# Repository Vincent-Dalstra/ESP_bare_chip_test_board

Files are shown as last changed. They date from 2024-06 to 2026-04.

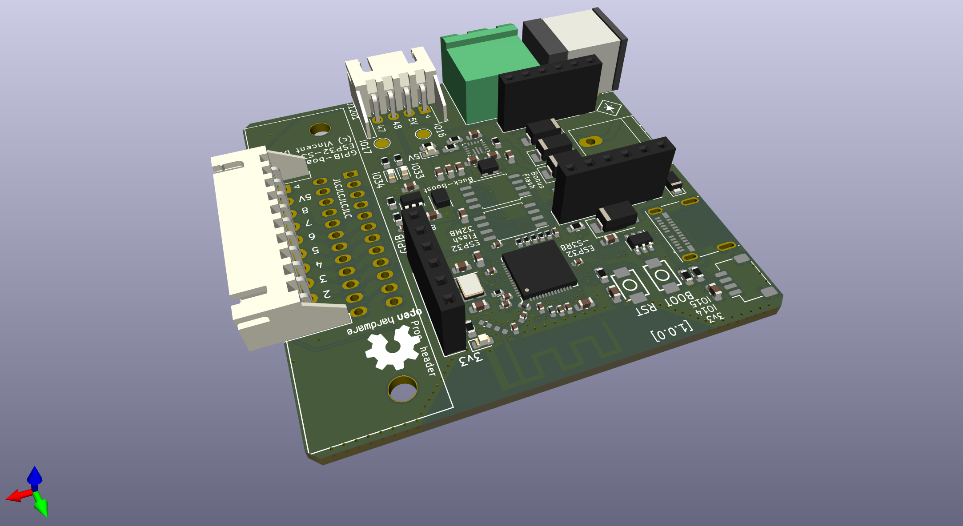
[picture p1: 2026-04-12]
Releases/v1.0.0/ESP_bare_chip_test_board_v1.1.0_corner_view.png

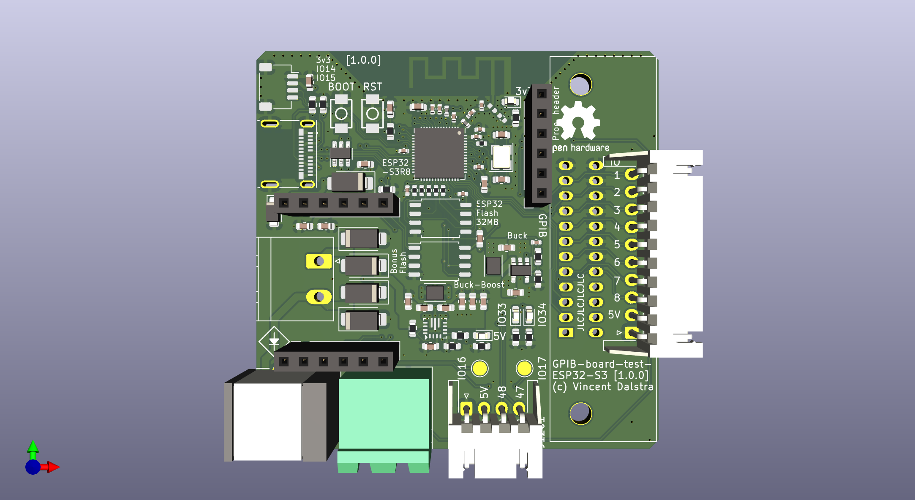
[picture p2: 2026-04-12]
Releases/v1.0.0/ESP_bare_chip_test_board_v1.1.0_top_view.png

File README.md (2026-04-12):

# ESP32 bare-chip test board / GPIB interface  #

This board primarily served as a practice design, to see if I could make a functioning esp32-s3 chip based circuit (not module!).
However, I prefer my boards to have a useful purpose rather than just being a paperweight, so decided to combine it with something else I was working on, which was to make an integrated verison of the boards in
https://github.com/Vincent-Dalstra/ESP32-GPIB-pcb, which saves having to use dev boards for this.

The code that it's expected to run can be found at https://github.com/douardda/AR488-ESP32
It is a very useful project, which allows an ESP32 to control various old (and new!) test-equipment.

## Features ##

* Versatile power-input options
  * USB-C port
  * Choice of barrel-jack or 5.08mm screw terminals
    * Works with either polarity - bridge rectifier
    * 3-17V input range
  * If both USB-C and another source are provided, the higher-voltage will be used.
* Wired or Wireless network connectivity
  * Slot for SPI Ethernet adapter (USR-ES1, based on W5500 chip)
  * WiFi/Bluetooth Antenna
* Non-volatile storage
  * 16MB flash via high-speed QIO connection
    * Used to store program code
    * Excess can be used for other purposes
  * 16MB flash via SPI bus
    * Shares the bus with Ethernet adapter
* Programmeable via USB-C port or (optional) 6pin UART header
* Connectors:
  * 24pin connector for GPIB, with 16 IO pins OR
    * alternatively a 10pin 2.50mm JST connector (8x IO, 5V, Gnd)
  * 4pin 1.00mm Piicodev-compatible connector
  * 4pin 2.50mm JST (2x IO, 5V, Gnd)
* Misc.
  * 2x Yellow Indicator LED's
  * 2x Test points that can be soldered to.

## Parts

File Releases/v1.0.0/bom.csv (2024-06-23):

Comment | Designator | Footprint | LCSC
10kΩ | R101,R102,R201,R202 | Resistor_SMD:R_0603_1608Metric | C25804
YELLOW | D101,D102 | LED_SMD:LED_0603_1608Metric | C72038
22uF/6.3V | C203,C1003,C1301,C1302,C1402 | Capacitor_SMD:C_0603_1608Metric | C59461
Conn_01x04 | J1501 | Connector_JST:JST_SH_SM04B-SRSS-TB_1x04-1MP_P1.00mm_Horizontal | C145956
100nF/50V | C201,C1401 | Capacitor_SMD:C_0603_1608Metric | C14663
GREEN | D201,D507 | LED_SMD:LED_0603_1608Metric | C779453
SW_Push | SW201,SW202 | Button_Switch_SMD_custom:SW_PUSHBUTTON_2PIN_SMD_3×4×2.0 | C720477
1uF | C304,C305,C307 | Capacitor_SMD:C_0402_1005Metric | C52923
40MHz | Q301 | Crystal:Crystal_SMD_3225-4Pin_3.2x2.5mm | C379787
10pF | C301,C302 | Capacitor_SMD:C_0603_1608Metric | C1634
0 | R302,R303,R304,R305,R306 | Resistor_SMD:R_0402_1005Metric | C203078
10nF | C308 | Capacitor_SMD:C_0402_1005Metric | C15195
W25Q128JVS | U301,U1401 | Package_SO:SOIC-8_5.23x5.23mm_P1.27mm | C97521
2.0nH(0.1nH) | L301 | Inductor_SMD:L_0402_1005Metric | C43365
0.1uF | C306,C309,C310,C311,C312 | Capacitor_SMD:C_0402_1005Metric | C307331
10uF/10V | C303,C1001,C1004,C1005,C1006,C1007 | Capacitor_SMD:C_0603_1608Metric | C19702
24nH | R301 | Resistor_SMD:R_0402_1005Metric | C330863
ESP32-S3R8 | U302 | Package_DFN_QFN:QFN-56-1EP_7x7mm_P0.4mm_EP5.6x5.6mm | C2913194
1.6nH | L401 | Inductor_SMD:L_0402_1005Metric | C162539
4.7pF | C401 | Capacitor_SMD:C_0402_1005Metric | C1569
2.7pF | C402 | Capacitor_SMD:C_0402_1005Metric | C1561
SS210 | D502,D503,D504,D505,D509 | Diode_SMD:D_SMA | C14996
SMF5V0A | D501 | Diode_SMD:D_SMF | C2905637
10uF/25v | C501,C1010,C1011 | Capacitor_SMD:C_0603_1608Metric | C96446
33kΩ | R506,R1002 | Resistor_SMD:R_0603_1608Metric | C4216
680kΩ | R1004 | Resistor_SMD:R_0603_1608Metric | C25822
130kΩ | R1005 | Resistor_SMD:R_0603_1608Metric | C22795
100nF | C1012 | Capacitor_SMD:C_0603_1608Metric | C14663
TPS63070 | U1002 | Package_DFN_QFN_custom:VQFN-15-HR_2.5x3mm_P0.5mm | C109322
100kΩ | R1003 | Resistor_SMD:R_0603_1608Metric | C25803
1.5uH | L1003 | Inductor_SMD:L_Changjiang_FNR252012S | C5832371
2.2uH | L1001 | Inductor_SMD:L_Changjiang_FNR252012S | C5832372
22pF | C1002 | Capacitor_SMD:C_0402_1005Metric | C1555
150kΩ | R1001 | Resistor_SMD:R_0603_1608Metric | C22807
TLV62569DBV | U1001 | Package_TO_SOT_SMD:SOT-23-5 | C141836
1.5kΩ | R1301 | Resistor_SMD:R_0603_1608Metric | C22843
D1213A-04TS-7 | U801 | Package_TO_SOT_SMD:TSOT-23-6 | C460588
5.1kΩ | R601,R602 | Resistor_SMD:R_0603_1608Metric | C23186
USB_C_Receptacle | J801 | Connector_USB:USB_C_Receptacle_Molex_105450-0101 | C134092

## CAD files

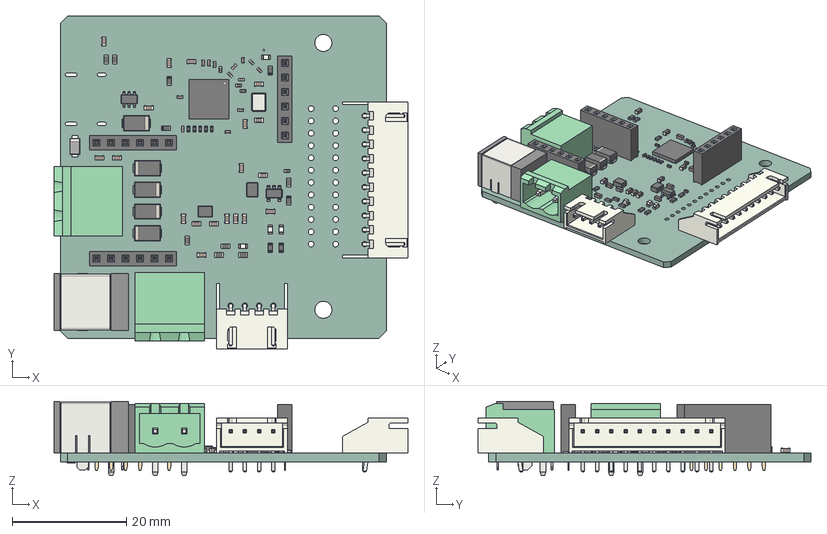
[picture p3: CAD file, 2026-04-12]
Releases/v1.0.0/ESP_bare_chip_test_board.step
62.0 x 58.4 x 13.0 mm
BarrelJack_CUI_PJ-063AH_Horizontal
C_0402_1005Metric x 13
R_0603_1608Metric x 13
C_0603_1608Metric x 19
L_Changjiang_FNR252012S x 2
JST_XH_S10B-XH-A-1_1x10_P2.50mm_Horizontal
L_0402_1005Metric x 3
PinSocket_1x06_P2.54mm_Vertical x 3
TSOT-23-6
R_0402_1005Metric x 6
D_SMA x 5
SOT-23-5
QFN-56-1EP_7x7mm_P0.4mm_EP5.6x5.6mm
D_SMF
Crystal_SMD_3225-4Pin_3.2x2.5mm
JST_XH_S4B-XH-A-1_1x04_P2.50mm_Horizontal
LED_0603_1608Metric x 4
PhoenixContact_MSTBA_2,5_2-G-5,08_1x02_P5.08mm_Horizontal x 2
ESP_bare_chip_test_board_PCB

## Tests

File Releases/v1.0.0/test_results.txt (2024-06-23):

So far, only simple intial testing has been done to verify that the board
'works', withot trying every feature in detail.

# Initial testing #

Boards arrived. Unpacked, look good.

## Power-up test ##

Plugged into USB power outlet w/ current meter
- 5V and 3v3 LED's light up ok
- Current draw reads 0.0A (<100mA)

All working as expected.

Also, touched both regulator circuits with fingers, thoroughly - no issues
- Some buck-regulators I've used would be be killed by this!

## Test code ##

Plugged into computer - shows up as /dev/ttyACM0

Used idf.py to compile and flash 'blink' sketch, after setting the blink
pin to IO33 (yellow LED), and setting it to not be an addressable LED!
- LED blinking ok
- Serial output ok

## Wifi test code ##

Compile and flashed the examples/wifi/scan to the board
- Found the local wireless network, from both AP's!
- Nearest one = single-brick wall + 8 metres

## See details about flash chip ##

Ran esptool.py flash_id

Output:

esptool.py v4.7.0
Serial port /dev/ttyACM0
Connecting....
Detecting chip type... ESP32-S3
Chip is ESP32-S3 (QFN56) (revision v0.2)
Features: WiFi, BLE, Embedded PSRAM 8MB (AP_3v3)
Crystal is 40MHz
MAC: f0:f5:bd:4a:2d:04
Uploading stub...
Running stub...
Stub running...
Manufacturer: ef
Device: 4018
Detected flash size: 16MB
Flash type set in eFuse: quad (4 data lines)
Hard resetting via RTS pin...

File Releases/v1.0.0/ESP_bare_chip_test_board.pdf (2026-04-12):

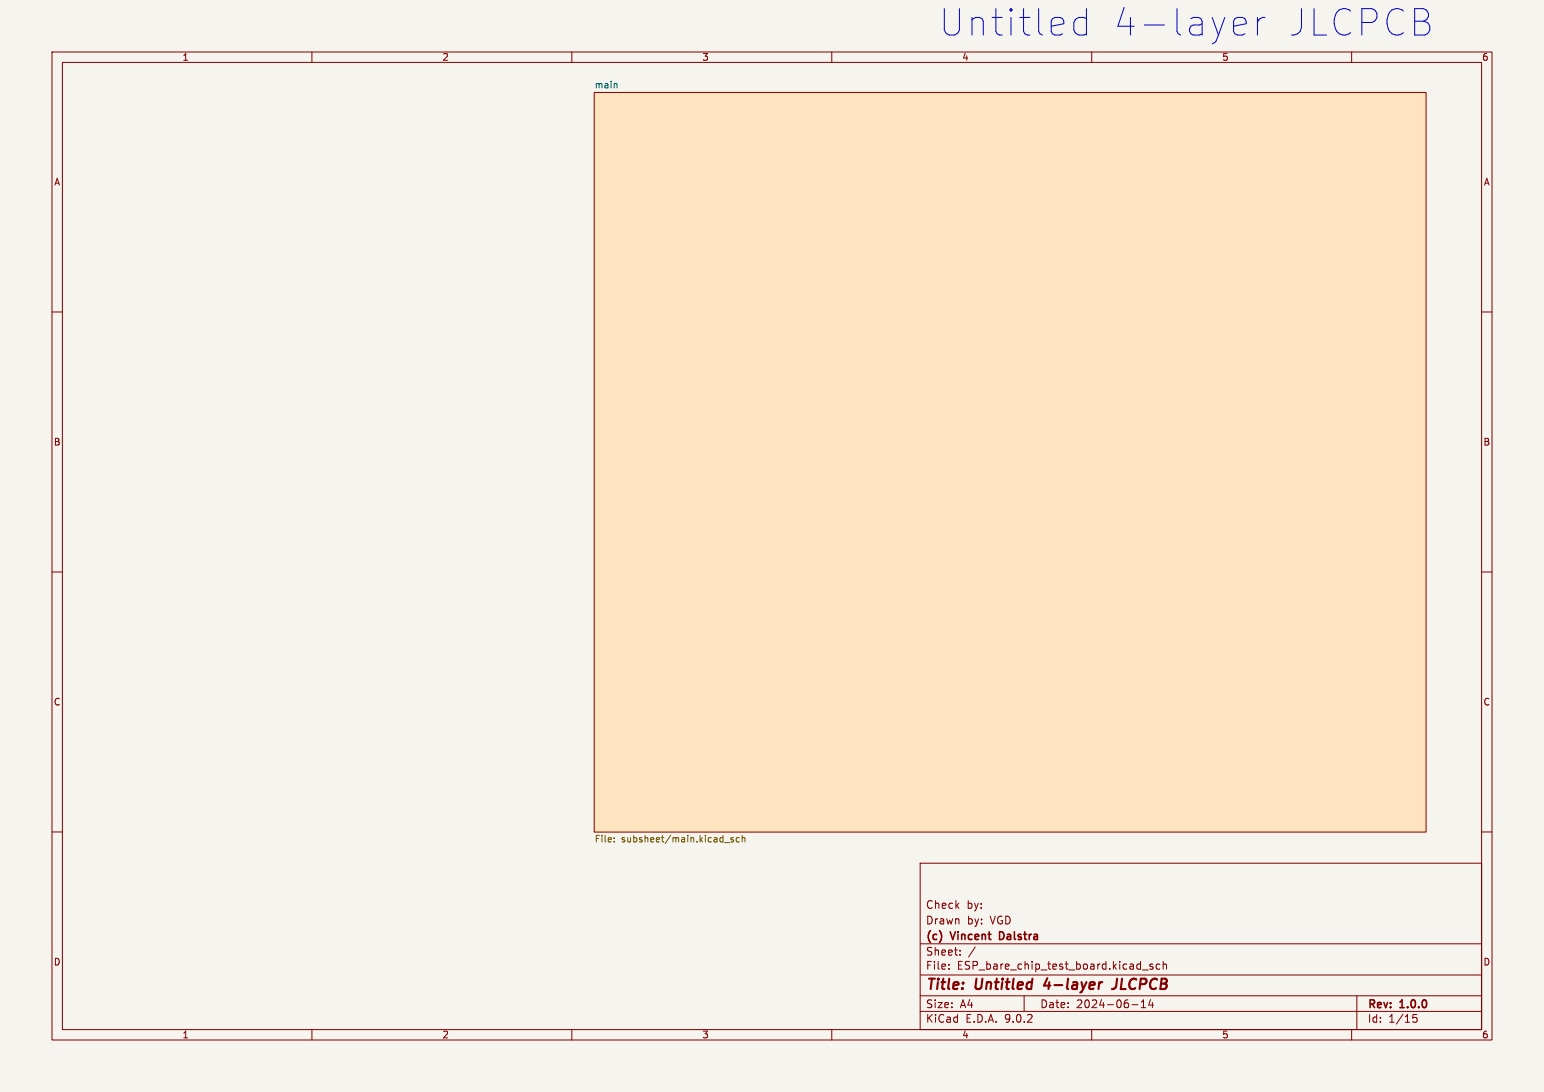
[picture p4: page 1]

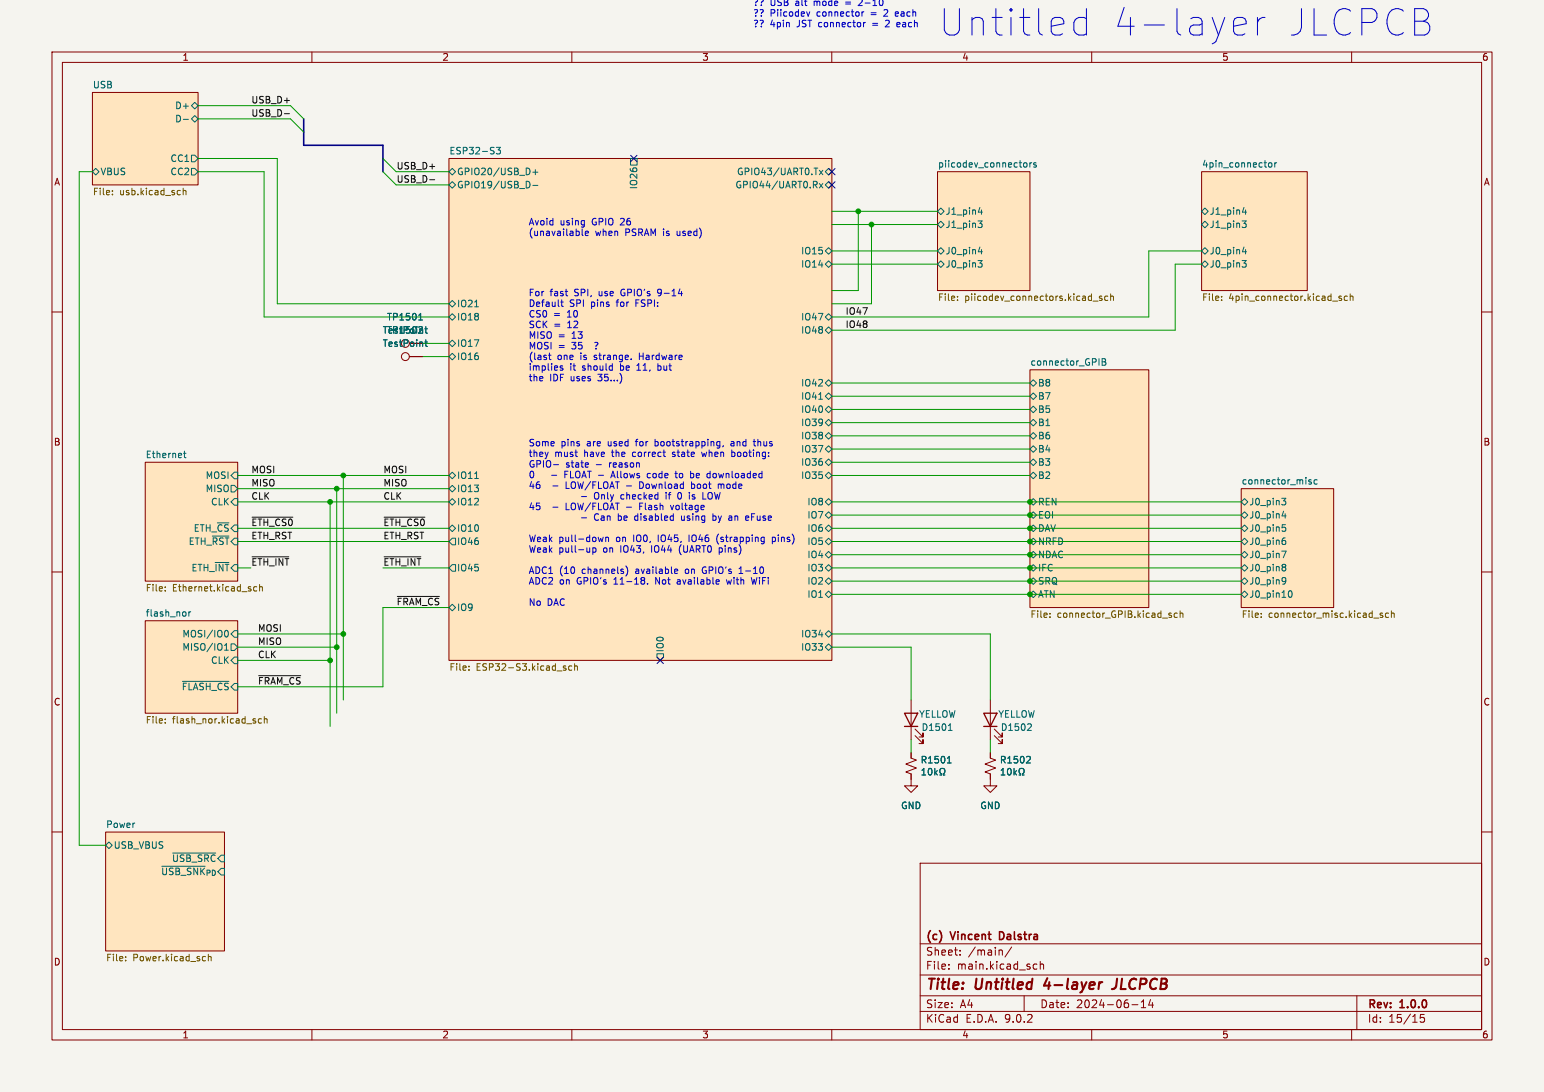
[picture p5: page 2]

(last one is strange. Hardware
the IDF uses 35...)

~{USB_SNK}_{PD} Power File: Power.kicad_sch CLK

they must have the correct state when booting: GPIO- state - reason

- Only checked if 0 is LOW

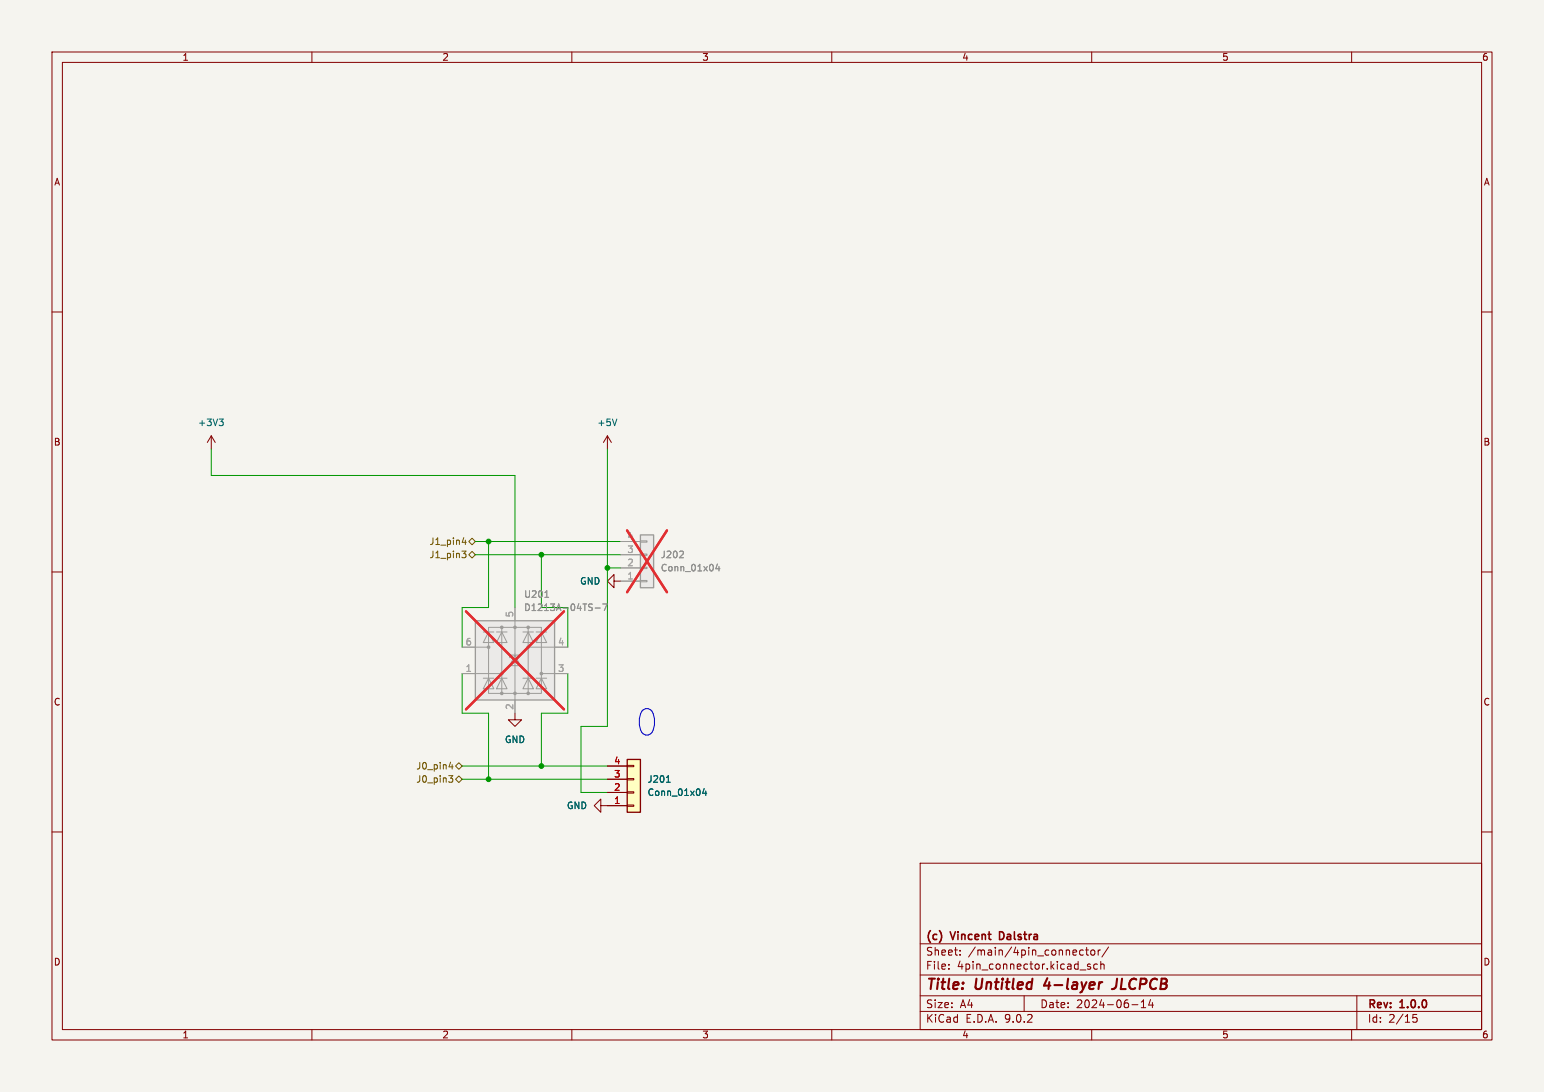
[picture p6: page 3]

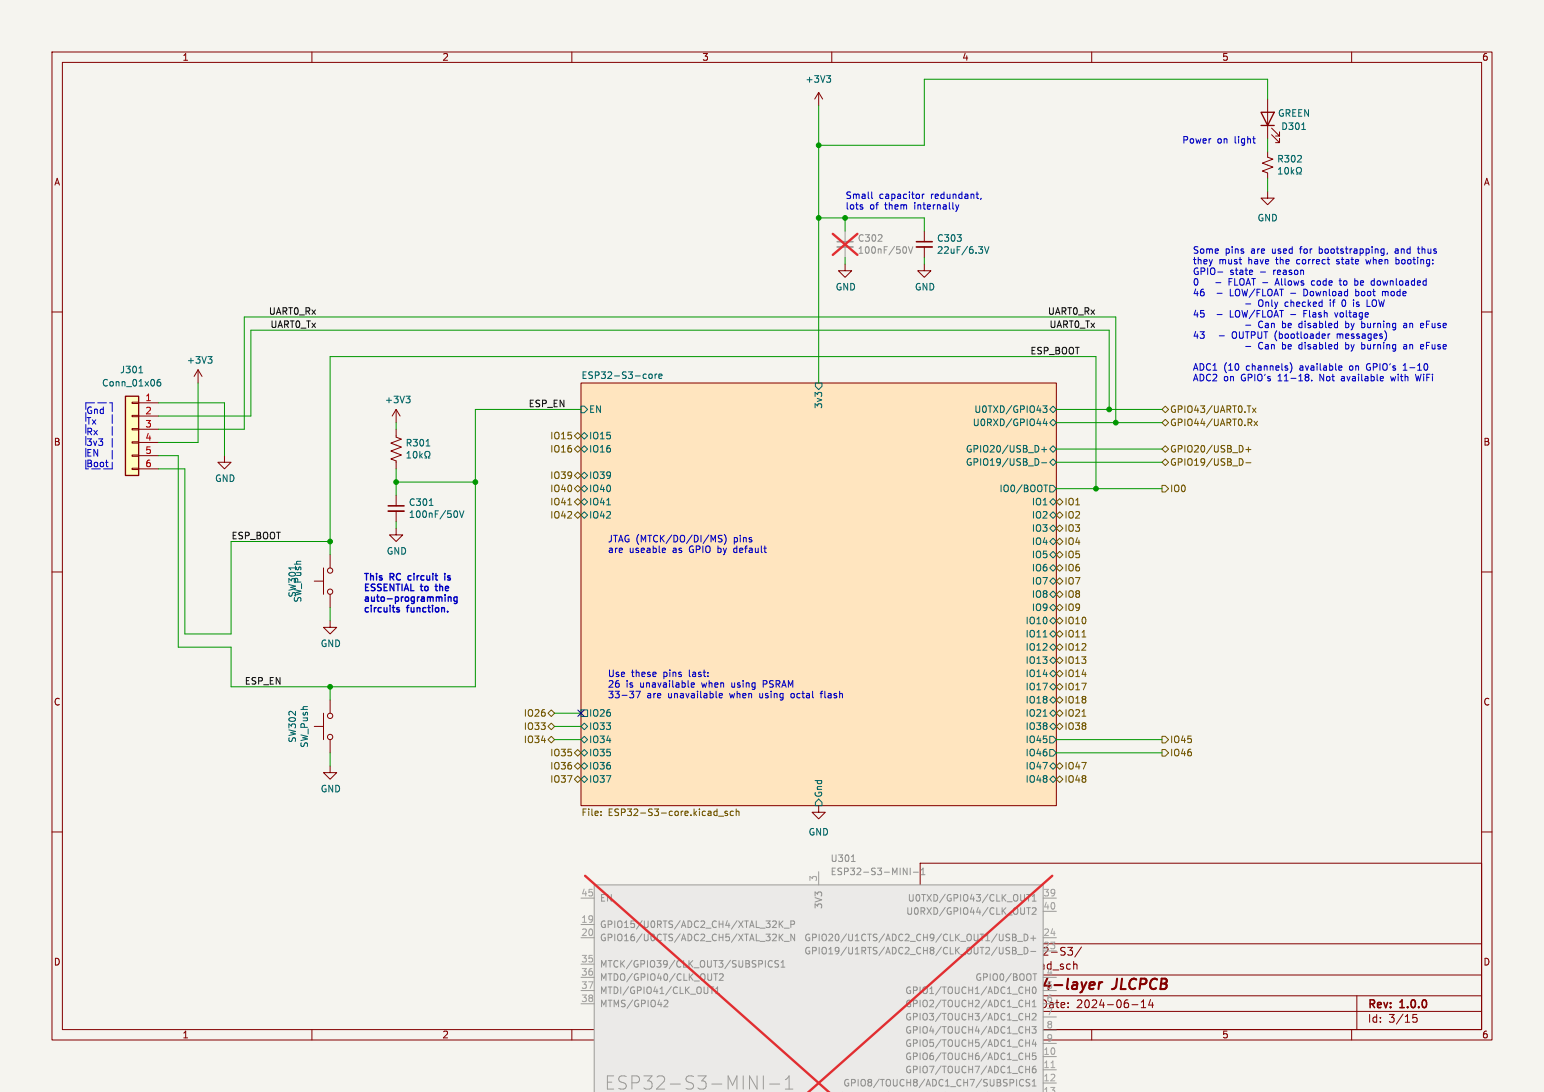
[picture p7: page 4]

they must have the correct state when booting: GPIO- state - reason

- Only checked if 0 is LOW

1 U0TXD/GPIO43/CLK_OUT1 39 U0RXD/GPIO44/CLK_OUT2 40 GPIO20/U1CTS/ADC2_CH9/CLK_OUT1/USB_D+ 24 GPIO19/U1RTS/ADC2_CH8/CLK_OUT2/USB_D- 23 GPIO0/BOOT 4 GPIO1/TOUCH1/ADC1_CH0 5 GPIO2/TOUCH2/ADC1_CH1 6 GPIO3/TOUCH3/ADC1_CH2 7 GPIO4/TOUCH4/ADC1_CH3 8 GPIO5/TOUCH5/ADC1_CH4 9 GPIO6/TOUCH6/ADC1_CH5 10 GPIO7/TOUCH7/ADC1_CH6 11 GPIO8/TOUCH8/ADC1_CH7/SUBSPICS1 12 GPIO9/TOUCH9/ADC1_CH8/FSPIHD/SUBSPIHD 13 GPIO10/TOUCH10/ADC1_CH9/FSPICS0/FSPIIO4/SUBSPICS0 14 GPIO11/TOUCH11/ADC2_CH0/FSPID/FSPIIO5/SUBSPID 15 GPIO12/TOUCH12/ADC2_CH1/FSPICLK/FSPIIO6/SUBSPICLK 16 GPIO13/TOUCH13/ADC2_CH2/FSPIQ/FSPIIO7/SUBSPIQ 17 GPIO14/TOUCH14/ADC2_CH3/FSPIWP/FSPIDQS/SUBSPIWP 18 GPIO17/U1TXD/ADC2_CH6 21 GPIO18/U1RXD/ADC2_CH7/CLK_OUT3 22 GPIO21 25 GPIO38/FSPIWP/SUBSPIWP 34 GPIO45 41 GPIO46 44 GPIO47/SPICLK_P/SUBSPICLK_P_DIFF 27 GPIO48/SPICLK_N/SUBSPICLK_N_DIFF 30 U301 ESP32-S3-MINI-1

File: ESP32-S3.kicad_sch Sheet: /main/ESP32-S3/ (c) Vincent by: VGD Dalstra Drawn

E.D.A. 9.0.2 Size: A4 | Rev: 1.0.0 | D Date: 2024-06-14 KiCad

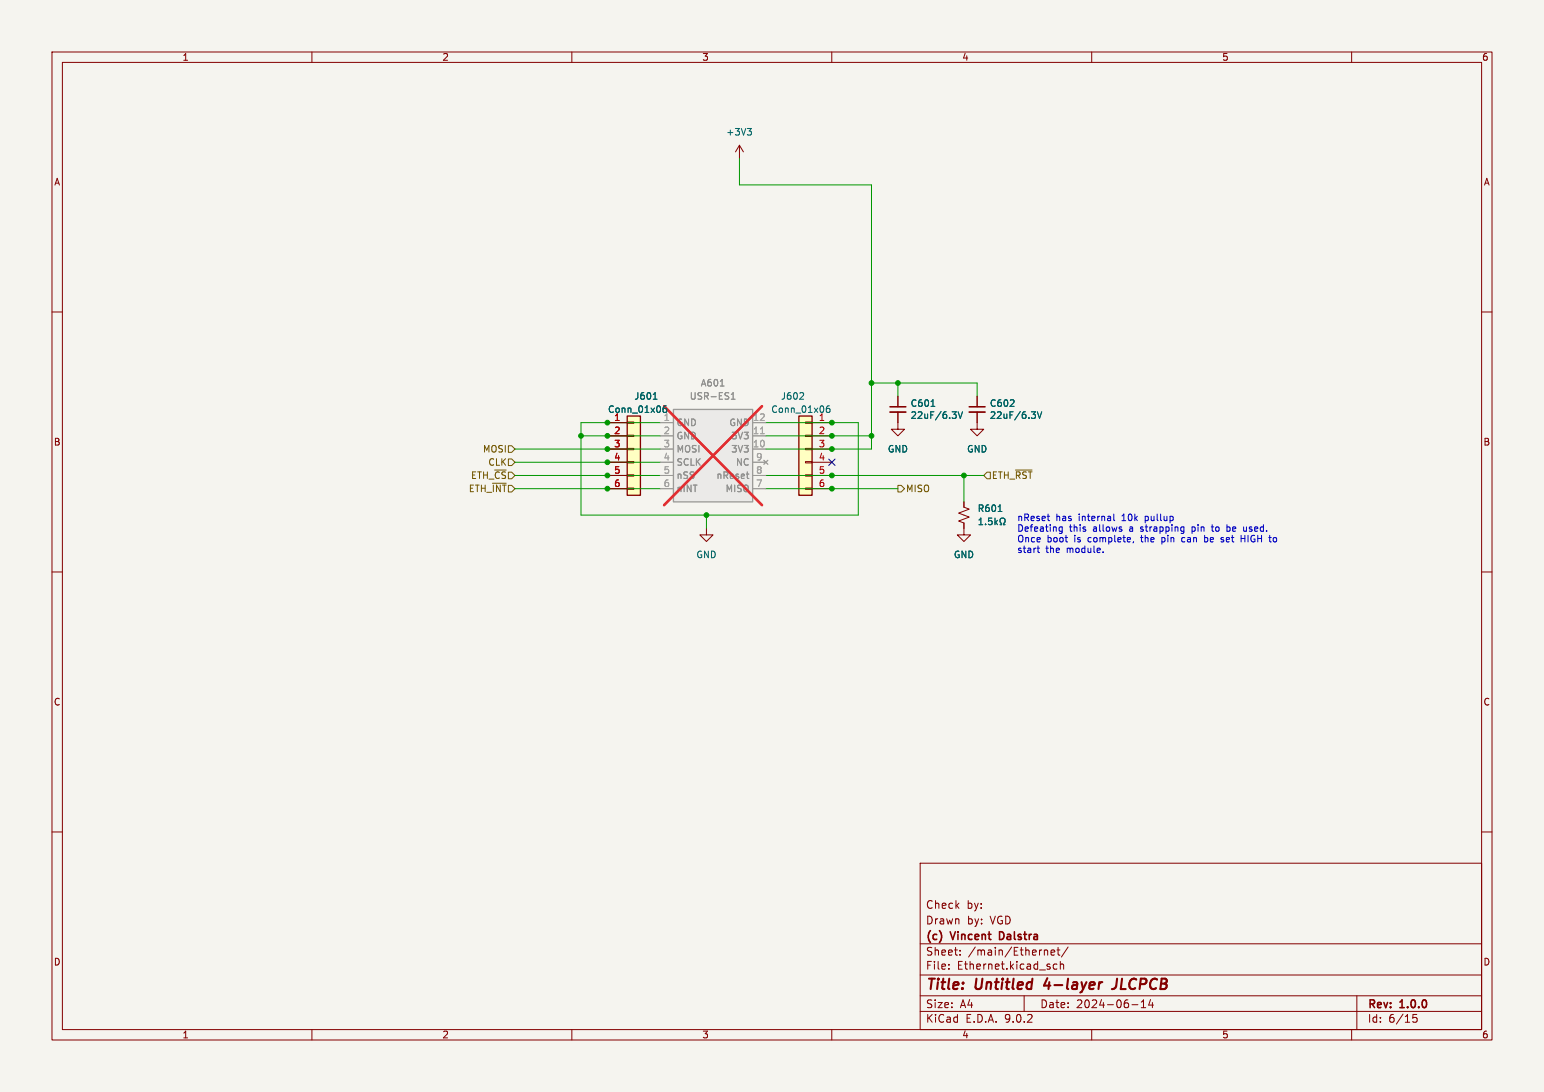
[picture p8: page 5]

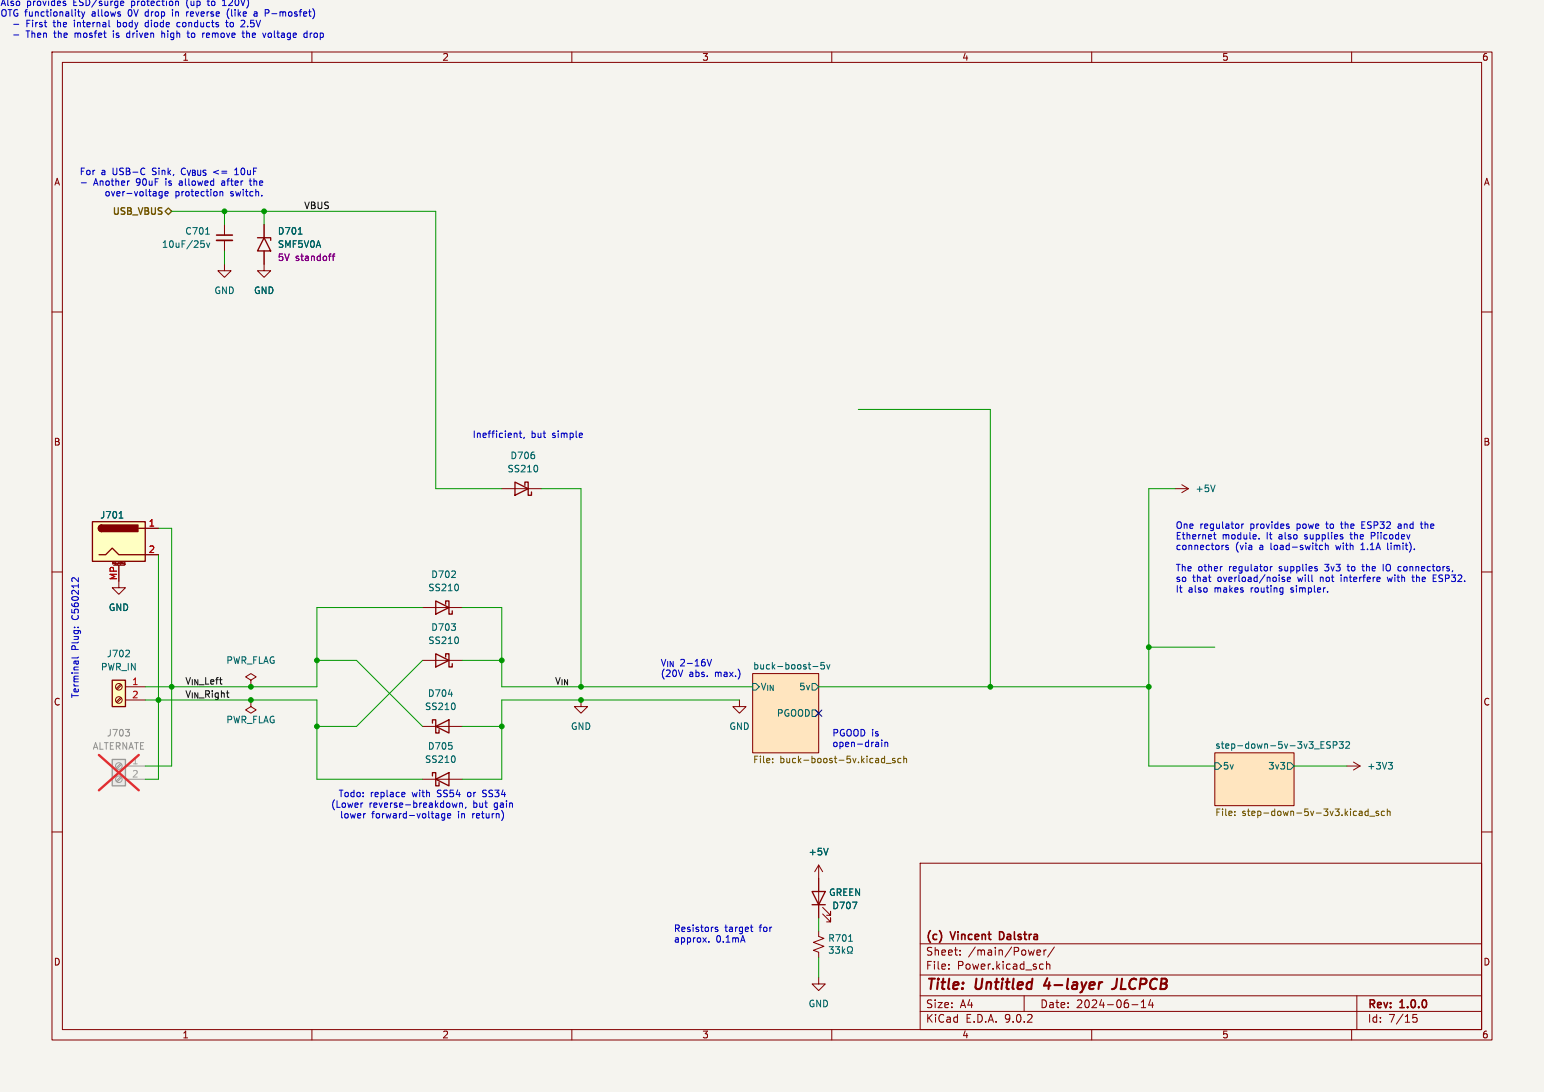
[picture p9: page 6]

- Then the mosfet is driven high to remove the voltage drop

For a USB-C Sink, C_{VBUS} <= 10uF
- Another 90uF is allowed after the
USB_VBUS

It also makes routing simpler. Override names

buck-boost-5v File: buck-boost-5v.kicad_sch D705

PGOOD is open-drain

step-down-5v-3v3_ESP32 File: step-down-5v-3v3.kicad_sch

Todo: replace with SS54 or SS34

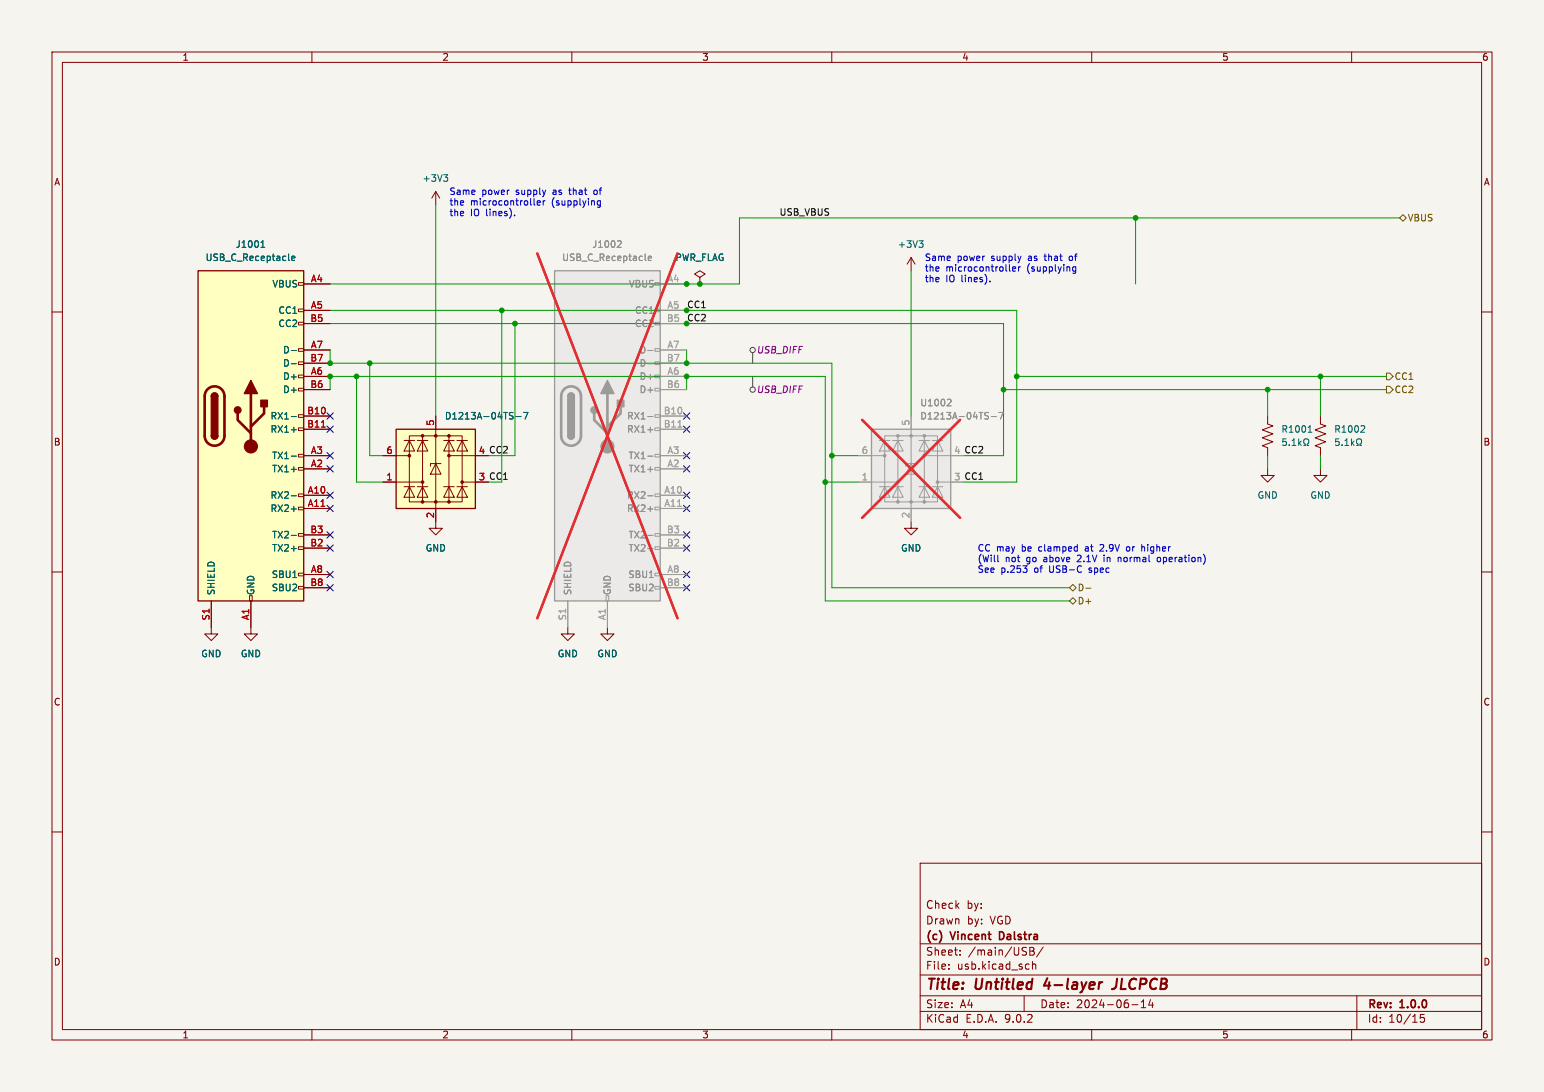
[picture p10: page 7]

(Will not go above 2.1V in normal operation) See p.253 of USB-C spec Same power supply as that of

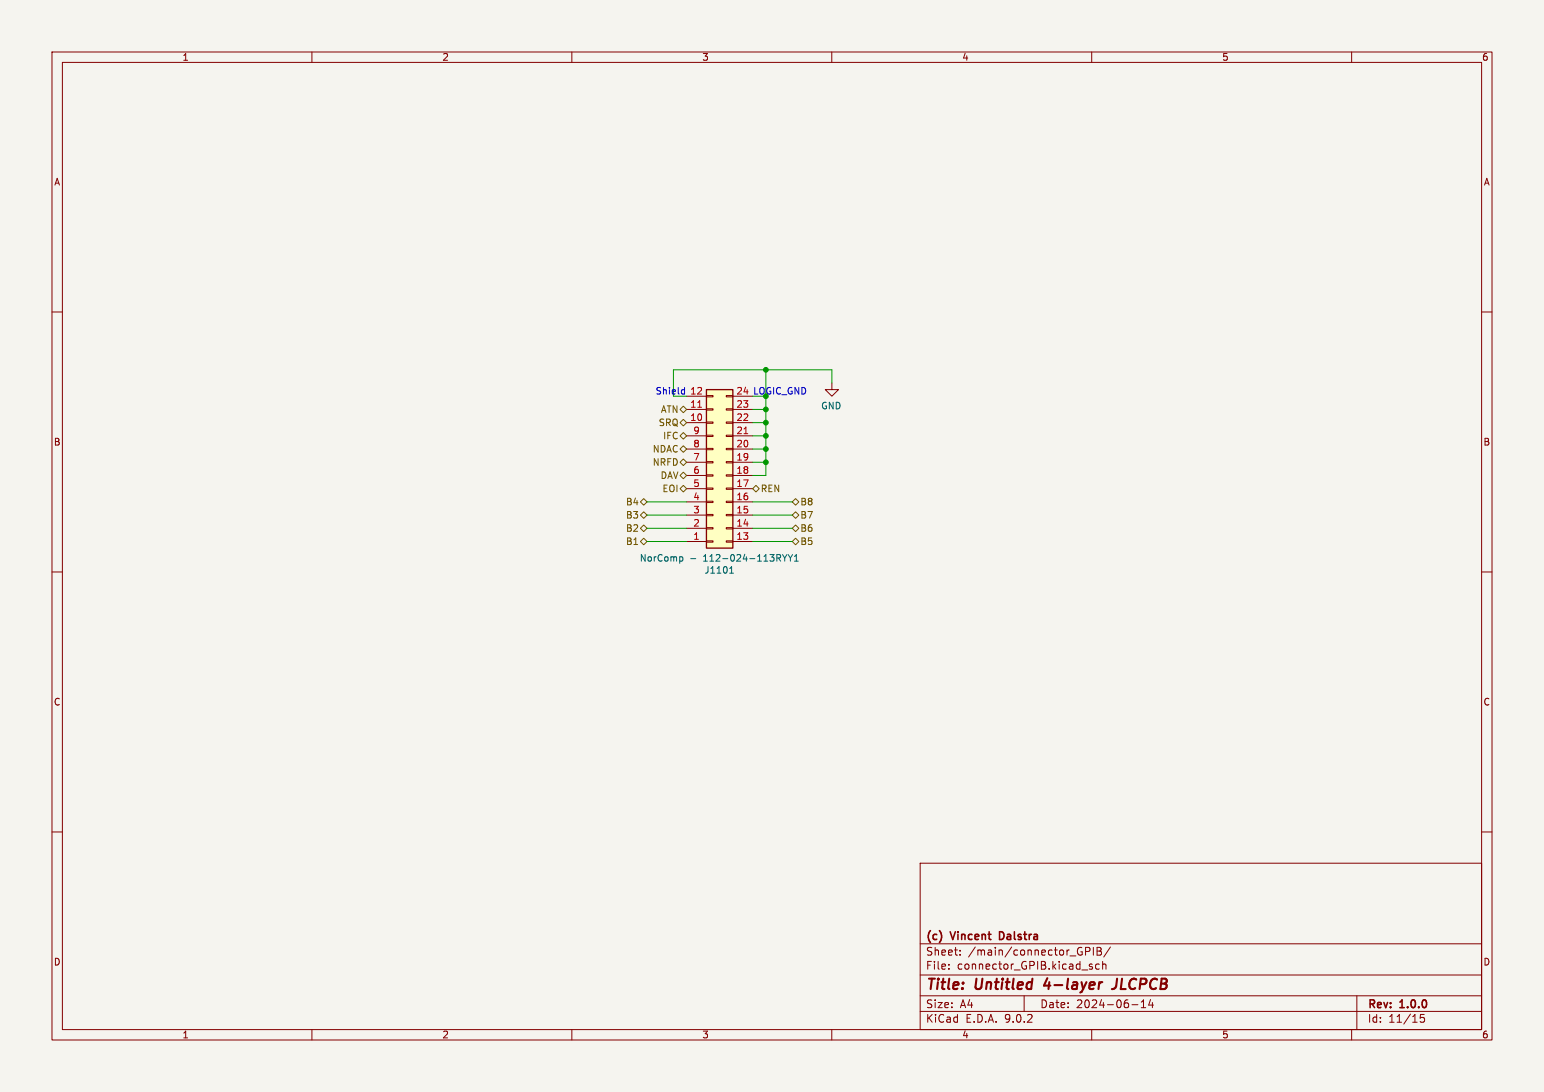
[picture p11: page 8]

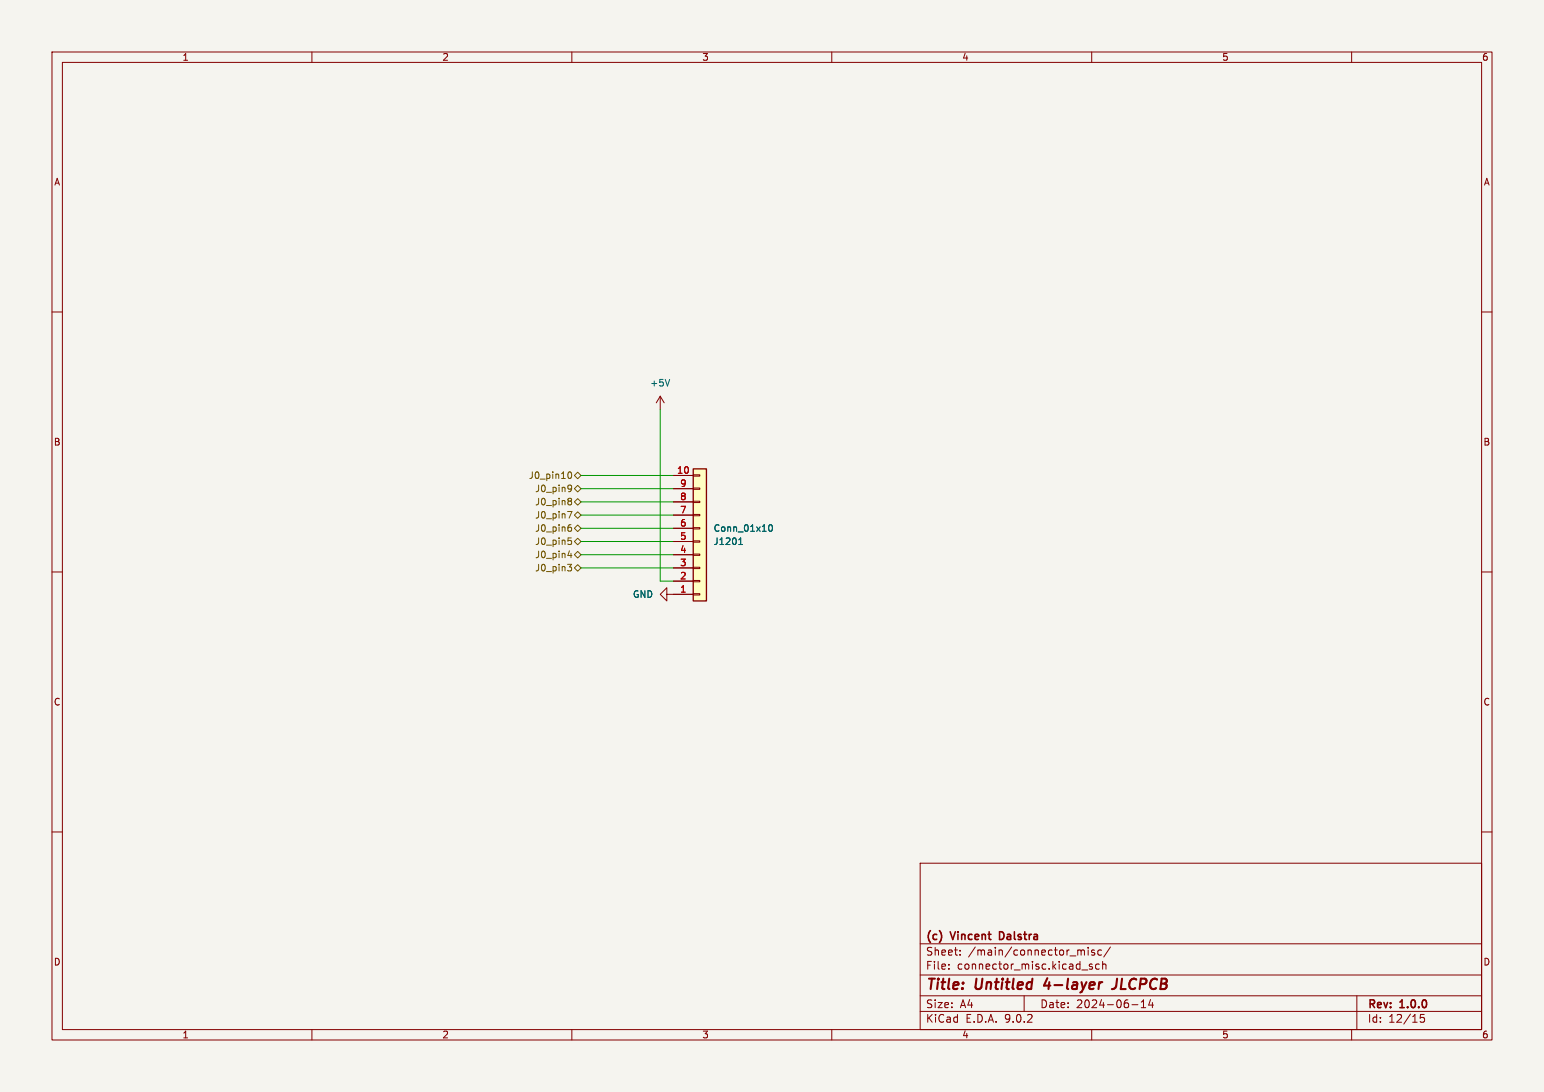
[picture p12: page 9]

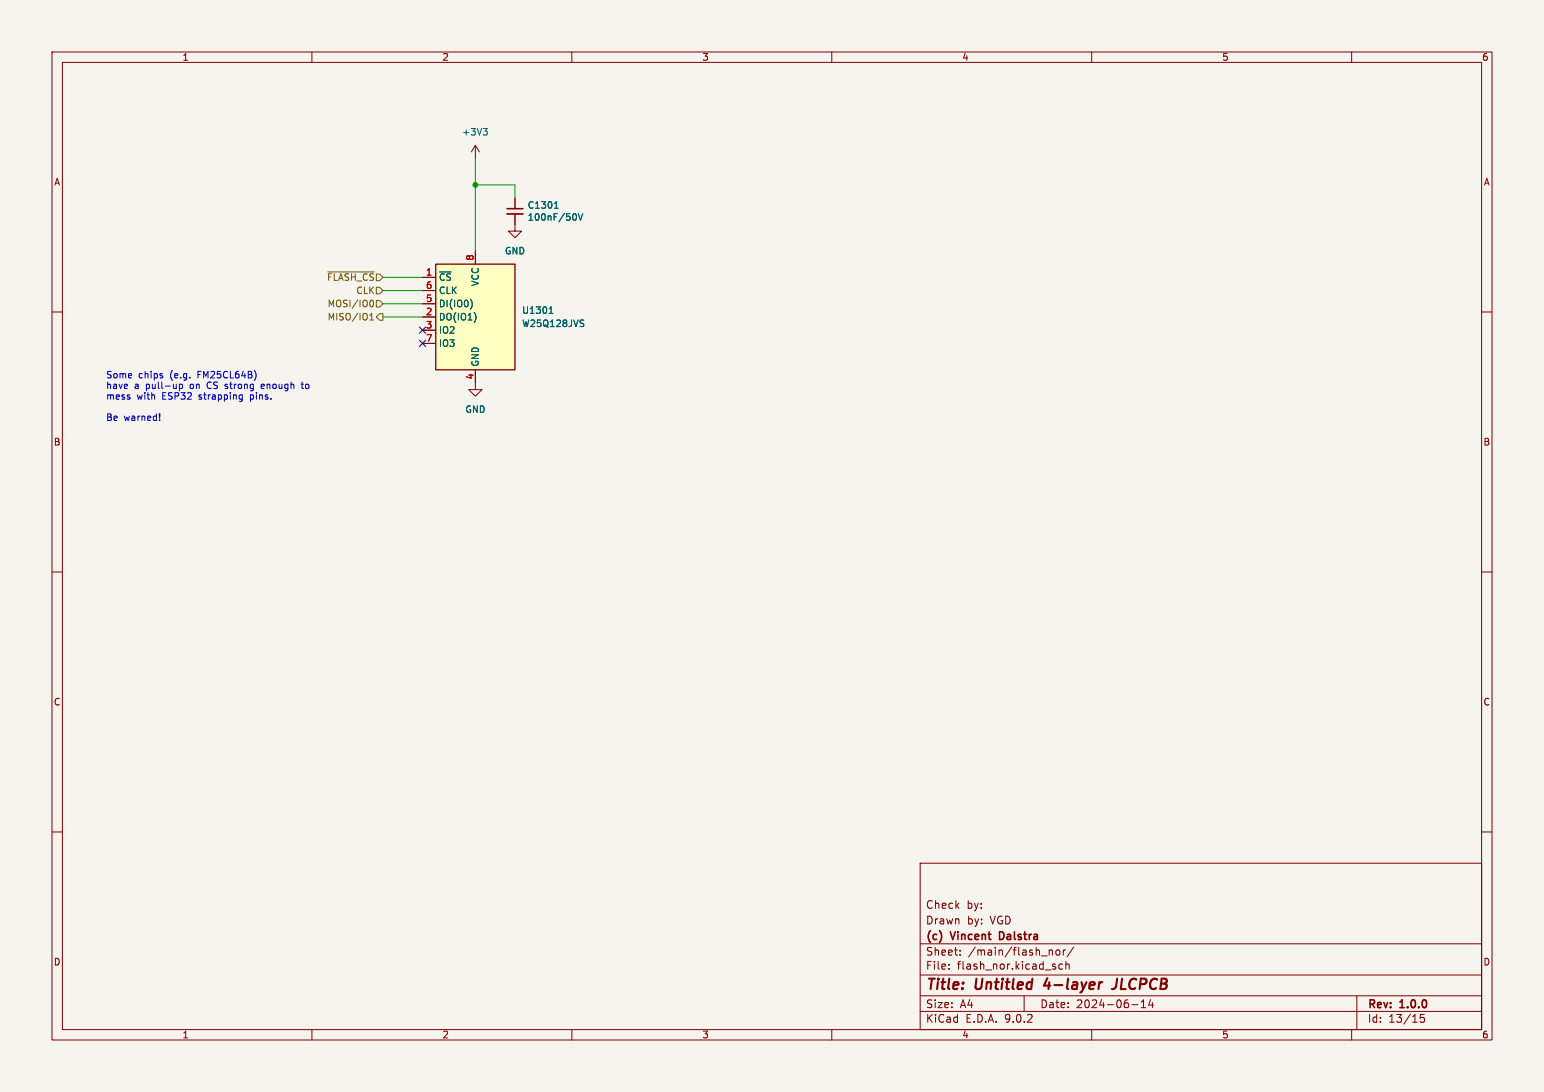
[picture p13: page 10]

4 U1301 W25Q128JVS GND MOSI/IO0 ~{FLASH_CS} CLK MISO/IO1 Some chips (e.g. FM25CL64B) have a pull-up on CS strong enough to mess with ESP32 strapping pins. Be warned! GND


Same power supply as that of

3 3 | Mounting 1


Power pins
- 10uF and 1uF are needed nearby, to supply burst power
antenna_experimental File: antenna_experimental.kicad_sch C402
VDD_SPI SPIWP
RF SPIQ

2 VDD3P3_RTC 20 VDD3P3_CPU 46 GND 57 VDDA 55 U0TXD/PROG/GPIO43 49 U0RXD/PROG/GPIO44 50 GPIO20/USB_D+/ADC2_CH9 26 GPIO19/USB_D-/ADC2_CH8 25 GPIO0/BOOT 5 GPIO1/ADC1_CH0 6 GPIO2/ADC1_CH1 7 GPIO3/ADC1_CH2 8 GPIO4/ADC1_CH3 9 GPIO5/ADC1_CH4 10 GPIO6/ADC1_CH5 11 GPIO7/ADC1_CH6 12 GPIO8/ADC1_CH7 13 GPIO9/ADC1_CH8 14 GPIO10/ADC1_CH9 15 GPIO11/ADC2_CH0 16 GPIO12/ADC2_CH1 17 GPIO13/ADC2_CH2 18 GPIO14/ADC2_CH3 19 GPIO17/ADC2_CH6 23 GPIO18/ADC2_CH7 24 GPIO21 27 GPIO38 43 GPIO45 51 GPIO46 52 GND GND GND

2 VDD3P3_RTC 20 VDD3P3_CPU 46 GND 57 VDDA 55 U0TXD/PROG/GPIO43 49 U0RXD/PROG/GPIO44 50 GPIO20/USB_D+/ADC2_CH9 26 GPIO19/USB_D-/ADC2_CH8 25 GPIO0/BOOT 5 GPIO1/ADC1_CH0 6 GPIO2/ADC1_CH1 7 GPIO3/ADC1_CH2 8 GPIO4/ADC1_CH3 9 GPIO5/ADC1_CH4 10 GPIO6/ADC1_CH5 11 GPIO7/ADC1_CH6 12 GPIO8/ADC1_CH7 13 GPIO9/ADC1_CH8 14 GPIO10/ADC1_CH9 15 GPIO11/ADC2_CH0 16 GPIO12/ADC2_CH1 17 GPIO13/ADC2_CH2 18 GPIO14/ADC2_CH3 19 GPIO17/ADC2_CH6 23 GPIO18/ADC2_CH7 24 GPIO21 27 GPIO38 43 GPIO45 51 GPIO46 52 U402 ESP32-S3R8

gnd, so long as the
layer below has a

to shield the crystal.


Giving SGND a separate via to the ground plane


File: step-down-5v-3v3.kicad_sch Sheet: /main/Power/step-down-5v-3v3_ESP32/


https://datasheet.lcsc.com/lcsc/1912111437_Maxscend-MXD8546FA_C462321.pdf
https://datasheet.lcsc.com/lcsc/2004132010_WILLSEMI-Will-Semicon-WS7808QC-14-TR_C506160.pdf
https://datasheet.lcsc.com/lcsc/2109141830_Shenzhen-Fuman-Elec-FM8625H_C2857391.pdf
https://datasheet.lcsc.com/lcsc/2109141830_Shenzhen-Fuman-Elec-FM1694C_C2857388.pdf
https://datasheet.lcsc.com/lcsc/1804151811_Skyworks-Solutions-SKY13373-460LF_C150853.pdf
https://datasheet.lcsc.com/lcsc/1811081217_Maxscend-MXD8544A_C285579.pdf
https://datasheet.lcsc.com/lcsc/1804151811_Skyworks-Solutions-SKY13317-373LF_C129190.pdf

File: antenna_experimental.kicad_sch Sheet: /main/ESP32-S3/ESP32-S3-core/antenna_experimental/

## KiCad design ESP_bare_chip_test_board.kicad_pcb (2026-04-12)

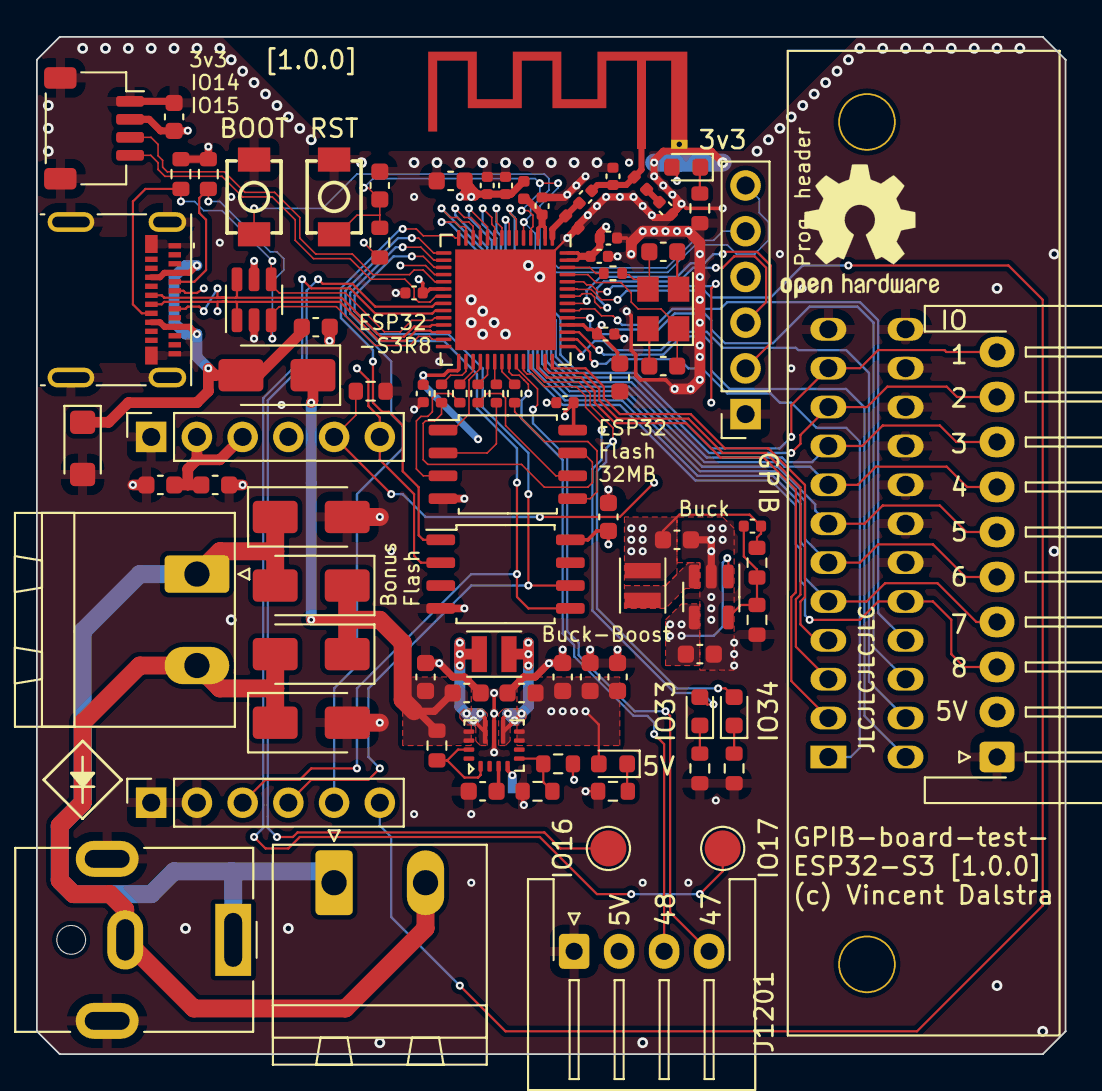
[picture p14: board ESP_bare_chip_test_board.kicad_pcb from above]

Board: 4 copper layers, 57.1 x 56.5 mm, 90 parts (1 on the bottom side), 79 nets.

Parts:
C201, C1401: 100nF/50V; C_0603_1608Metric
C203, C1003, C1301, C1302, C1402: 22uF/6.3V; C_0603_1608Metric
C301, C302: 10pF; C_0603_1608Metric
C303, C1001, C1004, C1005, C1006, C1007: 10uF/10V; C_0603_1608Metric
C304, C305, C307: 1uF; C_0402_1005Metric
C306, C309, C310, C311, C312: 0.1uF; C_0402_1005Metric
C308: 10nF; C_0402_1005Metric
C401: 4.7pF; C_0402_1005Metric
C402: 2.7pF; C_0402_1005Metric
C403: TBD; C_0402_1005Metric
C501, C1010, C1011: 10uF/25v; C_0603_1608Metric
C1002: 22pF; C_0402_1005Metric
C1012: 100nF; C_0603_1608Metric
D101, D102: YELLOW; LED_0603_1608Metric
D201, D507: GREEN; LED_0603_1608Metric
D501: SMF5V0A; D_SMF
D502, D503, D504, D505, D509: SS210; D_SMA
E401: ANTENNA-GROUNDEDTRACE-15.2MM; Texas_SWRA117D_2.4GHz_Left
J201, J1301, J1302: Conn_01x06; PinSocket_1x06_P2.54mm_Vertical
J501: Barrel_Jack; BarrelJack_CUI_PJ-063AH_Horizontal
J502: PWR_IN; Ningbo_Xinlaiya_XY2500R-D-5.08-2P_1x02_P5.08mm_Horizontal
J503: ALTERNATE; Ningbo_Xinlaiya_XY2500R-D-5.08-2P_1x02_P5.08mm_Horizontal
J801: USB_C_Receptacle; USB_C_Receptacle_Molex_105450-0101
J1101: Conn_01x04; JST_XH_S4B-XH-A-1_1x04_P2.50mm_Horizontal
J1201: NorComp - 112-024-113RYY1; CENTRONICS-24
J1303: Conn_01x10; JST_XH_S10B-XH-A-1_1x10_P2.50mm_Horizontal
J1501: Conn_01x04; JST_SH_SM04B-SRSS-TB_1x04-1MP_P1.00mm_Horizontal
L301: 2.0nH(0.1nH); L_0402_1005Metric
L401: 1.6nH; L_0402_1005Metric
L402: TBD; L_0402_1005Metric
L1001: 2.2uH; L_Changjiang_FNR252012S
L1003: 1.5uH; L_Changjiang_FNR252012S
NT901: NetTie_2; NetTie-2_SMD_Pad0.5mm
Q301: 40MHz; Crystal_SMD_3225-4Pin_3.2x2.5mm
R101, R102, R201, R202: 10kΩ; R_0603_1608Metric
R301: 24nH; R_0402_1005Metric
R302, R303, R304, R305, R306: 0; R_0402_1005Metric
R506, R1002: 33kΩ; R_0603_1608Metric
R601, R602: 5.1kΩ; R_0603_1608Metric
R1001: 150kΩ; R_0603_1608Metric
R1003: 100kΩ; R_0603_1608Metric
R1004: 680kΩ; R_0603_1608Metric
R1005: 130kΩ; R_0603_1608Metric
R1301: 1.5kΩ; R_0603_1608Metric
SW201, SW202: SW_Push; SW_PUSHBUTTON_2PIN_SMD_3×4×2.0
TP104, TP105: TestPoint; TestPoint_Pad_D2.0mm
U301, U1401: W25Q128JVS; SOIC-8_5.23x5.23mm_P1.27mm
U302: ESP32-S3R8; QFN-56-1EP_7x7mm_P0.4mm_EP5.6x5.6mm
U801: D1213A-04TS-7; TSOT-23-6
U1001: TLV62569DBV; SOT-23-5
U1002: TPS63070; VQFN-15-HR_2.5x3mm_P0.5mm

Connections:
+3V3: C203.1, C303.1, C304.1, C305.1, C306.1, C308.1, C311.1, C312.1, C1002.1, C1003.1, C1301.1, C1302.1, C1401.1, C1402.1, D201.2 (A), J201.4, J1302.2, J1302.3, J1501.2, L301.1, L1001.2, R201.1, R1001.1, U302.20 (VDD3P3_RTC), U302.46 (VDD3P3_CPU), U302.55 (VDDA), U302.56 (VDDA), U801.5 (VBUS), U1401.8 (VCC)
+5V: C1001.1, C1004.1, C1005.1, C1006.1, C1007.1, D507.2 (A), J1101.2, J1303.2, R1004.1, U1001.1 (EN), U1001.4 (VIN), U1002.7 (VOUT), U1002.8 (VOUT)
/CLK: J1301.4, U302.17 (GPIO12/ADC2_CH1), U1401.6 (CLK)
/ESP32-S3/ESP32-S3-core/RF: C401.1, L401.1, U302.1 (LNA_IN/RF)
/ESP32-S3/ESP32-S3-core/SPICLK: R304.1, U301.6 (CLK)
/ESP32-S3/ESP32-S3-core/SPICS0: U301.1 (~CS), U302.32 (SPICS0/GPIO29)
/ESP32-S3/ESP32-S3-core/SPID: R306.1, U301.5 (DI(IO0))
/ESP32-S3/ESP32-S3-core/SPIHD: R302.1, U301.7 (IO3)
/ESP32-S3/ESP32-S3-core/SPIQ: R305.1, U301.2 (DO(IO1))
/ESP32-S3/ESP32-S3-core/SPIWP: R303.1, U301.3 (IO2)
/ESP32-S3/ESP32-S3-core/VDD_SPI: C307.1, C310.1, U301.8 (VCC), U302.29 (VDD_SPI)
/ESP32-S3/ESP32-S3-core/antenna_experimental/50Ω ANT: C401.2, C402.1, E401.1 (A), L402.1
/ESP32-S3/ESP_BOOT: J201.6, SW201.2, U302.5 (GPIO0/BOOT)
/ESP32-S3/ESP_EN: C201.1, J201.5, R201.2, SW202.2, U302.4 (CHIP_PU/RESET)
/ESP32-S3/IO1: J1201.11, J1303.10, U302.6 (GPIO1/ADC1_CH0)
/ESP32-S3/IO2: J1201.10, J1303.9, U302.7 (GPIO2/ADC1_CH1)
/ESP32-S3/IO3: J1201.9, J1303.8, U302.8 (GPIO3/ADC1_CH2)
/ESP32-S3/IO4: J1201.8, J1303.7, U302.9 (GPIO4/ADC1_CH3)
/ESP32-S3/IO5: J1201.7, J1303.6, U302.10 (GPIO5/ADC1_CH4)
/ESP32-S3/IO6: J1201.6, J1303.5, U302.11 (GPIO6/ADC1_CH5)
/ESP32-S3/IO7: J1201.5, J1303.4, U302.12 (GPIO7/ADC1_CH6)
/ESP32-S3/IO8: J1201.17, J1303.3, U302.13 (GPIO8/ADC1_CH7)
/ESP32-S3/IO14: J1501.3, U302.19 (GPIO14/ADC2_CH3)
/ESP32-S3/IO15: J1501.4, U302.21 (GPIO15/ADC2_CH4/XTAL_32K_P)
/ESP32-S3/IO16: TP105.1, U302.22 (GPIO16/ADC2_CH5/XTAL_32K_N)
/ESP32-S3/IO17: TP104.1, U302.23 (GPIO17/ADC2_CH6)
/ESP32-S3/IO33: D101.2 (A), U302.38 (GPIO33)
/ESP32-S3/IO34: D102.2 (A), U302.39 (GPIO34)
/ESP32-S3/IO35: J1201.2, U302.40 (GPIO35)
/ESP32-S3/IO36: J1201.3, U302.41 (GPIO36)
/ESP32-S3/IO37: J1201.4, U302.42 (GPIO37)
/ESP32-S3/IO38: J1201.14, U302.43 (GPIO38)
/ESP32-S3/IO39: J1201.1, U302.44 (MTCK/JTAG/GPIO39)
/ESP32-S3/IO40: J1201.13, U302.45 (MTDO/JTAG/GPIO40)
/ESP32-S3/IO41: J1201.15, U302.47 (MTDI/JTAG/GPIO41)
/ESP32-S3/IO42: J1201.16, U302.48 (MTMS/JTAG/GPIO42)
/ESP32-S3/UART0_Rx: J201.3, U302.50 (U0RXD/PROG/GPIO44)
/ESP32-S3/UART0_Tx: J201.2, U302.49 (U0TXD/PROG/GPIO43)
/ETH_RST: J1302.5, R1301.2, U302.52 (GPIO46)
/IO47: J1101.4, U302.37 (SPICLK_P/GPIO47)
/IO48: J1101.3, U302.36 (SPICLK_N/GPIO48)
/MISO: J1302.6, U302.18 (GPIO13/ADC2_CH2), U1401.2 (DO(IO1))
/MOSI: J1301.3, U302.16 (GPIO11/ADC2_CH0), U1401.5 (DI(IO0))
/Power/VBUS: C501.1, D501.1 (A1), D509.2 (A), J801.A4 (VBUS), J801.A9 (VBUS), J801.B4 (VBUS), J801.B9 (VBUS)
/Power/V_{IN}: C1010.1, C1011.1, D502.1 (K), D503.1 (K), D509.1 (K), R1003.1, U1002.12 (VIN), U1002.13 (VIN)
/Power/V_{IN}_Left: D502.2 (A), D504.1 (K), J501.1, J502.1, J503.1
/Power/V_{IN}_Right: D503.2 (A), D505.1 (K), J501.2, J502.2, J503.2
/Power/buck-boost-5v/EN_{reg}: R1003.2, U1002.1 (PS/SYNC), U1002.14 (EN)
/Power/buck-boost-5v/FB: R1004.2, R1005.1, U1002.5 (FB)
/Power/buck-boost-5v/L1: L1003.1, U1002.11 (L1)
/Power/buck-boost-5v/L2: L1003.2, U1002.9 (L2)
/Power/buck-boost-5v/SGND: NT901.1, U1002.4 (GND)
/Power/buck-boost-5v/V_{AUX}: C1012.1, U1002.3 (VAUX)
/Power/step-down-5v-3v3_ESP32/FB: C1002.2, R1001.2, R1002.1, U1001.5 (FB)
/Power/step-down-5v-3v3_ESP32/SW: L1001.1, U1001.3 (SW)
/USB/CC1: J801.A5 (CC1), R602.2, U302.27 (GPIO21), U801.3 (I/O2)
/USB/CC2: J801.B5 (CC2), R601.2, U302.24 (GPIO18/ADC2_CH7), U801.4 (I/O3)
/USB_D+: J801.A6 (D+), J801.B6 (D+), U302.26 (GPIO20/USB_D+/ADC2_CH9), U801.1 (I/O1)
/USB_D-: J801.A7 (D-), J801.B7 (D-), U302.25 (GPIO19/USB_D-/ADC2_CH8), U801.6 (I/O4)
/~ETH_CS0: J1301.5, U302.15 (GPIO10/ADC1_CH9)
/~ETH_INT: J1301.6, U302.51 (GPIO45)
/~FRAM_CS: U302.14 (GPIO9/ADC1_CH8), U1401.1 (~CS)
GND: C201.2, C203.2, C303.2, C304.2, C305.2, C306.2, C307.2, C308.2, C309.2, C310.2, C311.2, C312.2, C402.2, C403.2, C501.2, C1001.2, C1003.2, C1004.2, C1005.2, C1006.2, C1007.2, C1010.2, C1011.2, C1012.2, C1301.2, C1302.2, C1401.2, C1402.2, D501.2 (A2), D504.2 (A), D505.2 (A), E401.2 (Shield), J201.1, J501.MP (MountPin), J801.A1 (GND), J801.A12 (GND), J801.B1 (GND), J801.B12 (GND), J801.S1 (SHIELD), J1101.1, J1201.12, J1201.18, J1201.19, J1201.20, J1201.21, J1201.22, J1201.23, J1201.24, J1301.1, J1301.2, J1302.1, J1303.1, J1501.1, J1501.MP (MountPin), L401.2, NT901.2, R101.2, R102.2, R202.2, R506.2, R601.1, R602.1, R1002.2, R1005.2, R1301.1, SW201.1, SW202.1, U301.4 (GND), U302.57 (GND), U801.2 (GND), U1001.2 (GND), U1002.10 (PGND), U1401.4 (GND)
unnamed: C301.2, Q301.4
unnamed: C302.1, Q301.3, R301.1
unnamed: C302.2, Q301.2
unnamed: C403.1, L402.2
unnamed: D101.1 (K), R101.1
unnamed: D102.1 (K), R102.1
unnamed: D201.1 (K), R202.1
unnamed: D507.1 (K), R506.1
unnamed: R304.2, U302.33 (SPICLK/GPIO30)
unnamed: R306.2, U302.35 (SPID/GPIO32)
unnamed: R302.2, U302.30 (SPIHD/GPIO27)
unnamed: R305.2, U302.34 (SPIQ/GPIO31)
unnamed: R303.2, U302.31 (SPIWP/GPIO28)
unnamed: C301.1, Q301.1, U302.53 (XTAL_N)
unnamed: R301.2, U302.54 (XTAL_P)
VDD3P3: C309.1, L301.2, U302.2 (VDD3P3), U302.3 (VDD3P3)

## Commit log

2023-12-12 Create from 4l template, copy in existing design
    Intent is to test the ESP32-S3 and ESP32-C3 bare chips (with qio flash
    IC and clock chip connected). If it works, it would greatly reduce the
    price of small-batch boards (because ESP32 modules cannot be placed in
    JLCPCB's economic assembly).
    Was already working on a design using an ESP32-S3 bare chip, so have
    copied int ehr elevant parts of that.
    [ESP32-S3-core.kicad_sch, ESP32-S3.kicad_sch, ESP_bare_chip_test_board.kicad_pcb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]
2024-03-27 Copy in component arrangement from SDMMC test design
    Already had an efficient arrangement for the SPI flash chip, Clock
    crystal, and Antenna.
    [ESP32-S3-core.kicad_sch, ESP32-S3.kicad_sch, ESP_bare_chip_test_board.kicad_pcb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]
2024-03-27 squash! Copy in component arrangement from SDMMC test design
    Using it as a template.
    [ESP_bare_chip_test_board.kicad_pcb]
2024-03-28 Update file format to KiCAD 8.0.0
    [ESP32-C3.kicad_sch, ESP32-S3-core.kicad_sch, ESP32-S3.kicad_sch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]
2024-03-28 Add ESP32-C3 subsheet. SMall corrections
    Add and wire up ESP32-C3-Mini on a subsheet, and note down which pins
    are used for strapping etc. This will then be replaced with a bare-chip
    ESP32-C3 circuit, much like with the existing ESP32-S3 circuit.
    [ESP32-C3.kicad_sch, ESP32-S3.kicad_sch, ESP_bare_chip_test_board.kicad_sch]
2024-03-30 Add sheet for ESP32-C3 bare chip as well.
    Similar to the ESP32-S3 circuit, so I copied most of it (one capacitor
    is not needed, according to the reference schematics).
    No flash chip is attached; makes sense to use one of the embedded flash
    chips to test with, as it makes for a very small design (and 16MB is
    really not needed).
    [ESP32-C3-core.kicad_sch, ESP32-C3.kicad_sch]
2024-04-07 Add 5v and 3v3 buck regulators, brige rectifier
    Buck regulators are copied from existing designs. 5V regulator needs to
    be reworked though; due to ESD vulnerability.
    Added 4 diodes in bridge rectifier configuration. Provides a simpler
    solution than the polarity-protected eFuse. Due to how the
    buck-regulators work, it should be fine for any voltage from ~4.8V 17V
    (max Vin of buck regulator). Downside is icnreased power-dissipation,
    but since this board is not intended to use a lot of current it should
    be good (the USB port can bypass this too, but only for 5V)
    [ESP_bare_chip_test_board.kicad_sch, Power.kicad_sch, step-down-12v-5v.kicad_sch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]
2024-04-18 PCB changes, added useful connectors
    Added a whole bunch of things that should make it useful - e.g.
    ethernet, an extra flash chip for general storage, piicodev connectors
    for I2C.
    Also added a GPIB connector footprint; dev-board version worked nicely,
    but may as well make this work for that too. Saves bying dev boards : )
    [ESP32-C3.kicad_sch, ESP32-S3.kicad_sch, ESP_bare_chip_test_board.kicad_pcb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]
2024-04-18 Add barrel jack to schematic
    [ESP_bare_chip_test_board.kicad_sch, Power.kicad_sch]
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2024-05-13 Unknown changes? Arranging components, I believe
    [ESP32-S3-core.kicad_sch, ESP32-S3.kicad_sch, ESP_bare_chip_test_board.kicad_pcb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]
2024-05-13 Apply XOR to 5V buck reg and USB power
    Some 5V regulators will be very unhappy if a higher-voltage is applied -
    e.g. from USB. Therefore, use a comparator to turn off the load-switch
    when 12V power is present.
    Circuit got a bit more complex because it needs to deal with dynamic
    situations as things are plugged in. Will still need some work, likely.
    [Power.kicad_sch]
2024-05-19 Replace buck-regulator with buck-boost regulator
    Replaced the buck-regulator with a buck-boost regulator. The primary
    purpose is because the buck-regulator could fail when a higher-voltage
    output was conected. The buck-regulators internal switches and design
    should be much less vulnerable for this.
    A second benefit of the buck-boost regulator is thata 5V input can now
    still be used, as it accounts for the voltage-drop from the
    bridge-rectifier diodes.
    [ESP_bare_chip_test_board.kicad_sch, Power.kicad_sch, buck-boost-5v.kicad_sch]
2024-05-19 Removed complex OR'ing circuit
    Replaced it with a simple one that will turn off the USB 5V switch when
    the buck-regulator is providing power (using PGOOD pin to signal this).
    May not even be necessary, but good to have.
    [Power.kicad_sch, buck-boost-5v.kicad_sch]
2024-05-19 Arranged buck-boost regulator. Moved some components slightly.
    [ESP_bare_chip_test_board.kicad_pcb, Power.kicad_sch, buck-boost-5v.kicad_sch]
2024-05-23 Removed USB-PD circuit - simplifies board
    [ESP_bare_chip_test_board.kicad_pcb, ESP_bare_chip_test_board.kicad_sch, Power.kicad_sch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]
2024-05-23 Layed-out 5V buck-boost regulator ciruit
    [ESP_bare_chip_test_board.kicad_pcb, buck-boost-5v.kicad_sch]
2024-05-23 Planning/wiring up some traces on PCB
    [ESP_bare_chip_test_board.kicad_pcb, Power.kicad_sch]
2024-05-23 Picked part numbers and placed most remaining MCU support components
    [ESP32-S3-core.kicad_sch, ESP32-S3.kicad_sch, ESP_bare_chip_test_board.kicad_pcb]
2024-05-28 Started wiring up traces
    [4pin_connector.kicad_sch, ESP_bare_chip_test_board.kicad_pcb, ESP_bare_chip_test_board.kicad_sch]
2024-05-28 Fixup ESP flash memory wiring
    One of the wires was missing, so added it. Rearranged wiring to allow it
    to fit without having to via across layers.
    [ESP_bare_chip_test_board.kicad_pcb]
2024-05-28 More wiring - Ethernet, SPI flash
    [ESP_bare_chip_test_board.kicad_pcb, ESP_bare_chip_test_board.kicad_sch, connector_GPIB.kicad_sch]
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2024-06-13 Position final few components
    Removed one ESD diode arrray - experimental board, so not really needed,
    with the exception of the USB lines.
    Add and position 5V indicator LED
    Finished wiring up the 5V buck-boost regulator
    [4pin_connector.kicad_sch, ESP_bare_chip_test_board.kicad_pcb, ESP_bare_chip_test_board.kicad_sch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]
2024-06-13 Wire remaining traces, fix DRC errors
    [ESP_bare_chip_test_board.kicad_pcb, ESP_bare_chip_test_board.kicad_sch, piicodev_connectors.kicad_sch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]
2024-06-13 Add test pads for extra IO pins
    Can be soldered to if desired for some testing purpose
    [ESP_bare_chip_test_board.kicad_pcb, ESP_bare_chip_test_board.kicad_sch]
2024-06-13 Free up IO26 (to allow for PSRAM)
    Had spare IO lines, so may as well use a different one to do ETH_INT
    instead of IO26.
    [ESP_bare_chip_test_board.kicad_pcb, ESP_bare_chip_test_board.kicad_sch]
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2024-06-13 Switch to ESP32-S3R8 (8Mb PSRAM)
    Switch to the ESP32-S3 chip that has integrated PSRAM, so I can test it
    Disadvantage is it means IO26 cannot be used, and is more expensive.
    Still uses external flash chip.
    [ESP32-S3-core.kicad_sch]
2024-06-13 Add JLCPCB corrections for new components
    [4pin_connector.kicad_sch, ESP32-S3-core.kicad_sch, ESP32-S3.kicad_sch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]
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2024-06-23 Final corrections and silkscreen labels
    [ESP_bare_chip_test_board.kicad_pcb, buck-boost-5v.kicad_sch, step-down-5v-3v3.kicad_sch]
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2025-07-15 Move all subsheets into 'main' subsheet, below root
    Keeping all the subsheets in a dedicated 'subsheet' folder makes things
    much, much neater. However, specifying filepaths for subsheets has an
    interesting problem; they use paths RELATIVE TO THE PARENT SHEET.
    The consequence of is that if a subsheet is part of the root sheet, it
    needs to be prefixed with 'subsheet/', but NOT if it's further down.
    This inconsistency can be resolved by having a single 'main' sheet at
    the top that doesn't move.
    It's also useful to have a top-level space to put down changelogs,
    descriptions etc.
    [4pin_connector.kicad_sch, ESP32-S3-core.kicad_sch, ESP32-S3.kicad_sch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]
2025-07-15 Remove unused sheets.
    Inherited from a different project used as a template for this one, but
    not used here.
    [ESP32-C3-core.kicad_sch, ESP32-C3.kicad_sch]
2026-04-12 Update Makefile (improvements)
    Improvements to Makefile scripts over time in other projects.
    - Generate docs as well (schematic, 3D model)
    - Don't generate redundant gerbers.zip
    - Fix dependency relationships between Makefile targets
    - Pinion
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2026-04-12 Add schematics and 3D-model for v1.0.0
    Updated Makefile now creates these automatically, so there's little
    effort required to add them in.
    [ESP_bare_chip_test_board.step]
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

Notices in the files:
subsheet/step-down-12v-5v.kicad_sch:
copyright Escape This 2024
